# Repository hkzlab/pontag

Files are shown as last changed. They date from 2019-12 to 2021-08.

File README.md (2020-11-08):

# PONTAG
## Introduction
PONTAG is a board that converts a PS/2 mouse into a serial mouse that can be used on old IBM PC and clones, which lacked PS/2 ports but had plenty of serial interfaces (especially if expansion cards are installed).

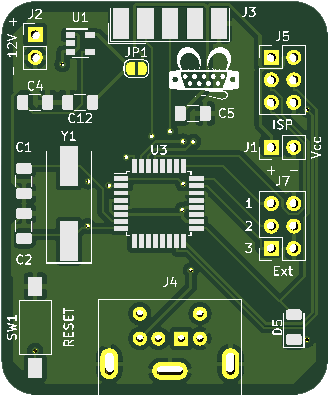
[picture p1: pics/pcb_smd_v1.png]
Rev. 1 PCB


## Features & Limitations
* Supports 3 buttons+wheel PS/2 mouses and converts their protocol to RS232 serial usable on old PC systems.
* The board requires an external power supply between 8V and 12V to power the MCU and mouse
* Detects PS/2 mouses with wheel and without and notifies the user via LED (5 fast blinks for a normal mouse, 20 fast blinks for a mouse with wheel)
* Can be configured for various resolutions and mouse protocols by pushing mouse buttons

### Configuration
The board can be configured during powerup by pressing the mouse keys. The configuration will be retained for all subsequent boots.
To configure the board you must keep the mouse button pressed during a reset/bootup. A sequence of **15 slow blinks** will notify the user of the accepted command, then the board will be reset with the new configuration.

* **Left mouse button pressed**: Switches between simple Microsoft protocol and Microsoft protocol with wheel (**DEFAULT:** MS+Wheel)
* **Right mouse button pressed**: Switches mouse resolution, switching between 1, 2, 4 or 8 counts per mm traveled (**DEFAULT:** 4 counts per mm)
* **Both buttons pressed**: Resets the board to defaults

### Extra Header
The board supports some special options that can be toggled via external header, shorting the corrisponding pin to GND.

* **Pin 1**: The board will enter debug mode, and start printing debug strings on the serial port. It will NOT work as a mouse.
* **Pin 2**: If jumpered, the board enter power save mode after 3 minutes of mouse inactivity.
* **Pin 3**: If shorted, forces the use of the simple Microsoft protocol (2 buttons, no wheel), regardless of what is stored in the EEPROM.
* **Pin 4**: If jumpered, the board will skip the PS/2 intellimouse wheel activation sequence. (**not exposed on board 1.0 !!!**)

## Supported protocols
PONTAG emulates a Microsoft 3-buttons Wheel serial mouse by default and transmits the `0x4D 0x5A 0x40 0x00 0x00 0x00` detection string when RTS signal is toggled.

The boards are tested with [CuteMouse](http://cutemouse.sourceforge.net/).

## Credits

- Some footprints are taken from [4x1md](https://github.com/4x1md/kicad_libraries)
- Took and modified PS/2 code from [sensi.org](http://sensi.org/~svo/%5Bm%5Douse/) and [mouse1351](https://github.com/svofski/mouse1351)

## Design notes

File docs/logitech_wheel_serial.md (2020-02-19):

A logitech serial mouse with wheel presents itself with the following sequence:
```
0x4D - 'M'
0x5A - 'Z'
0x40 - '@'
0x00
0x00
0x00
```

These bytes are also followed by this sequence
```
0x08 0x01 0x24 0x2c
0x27 0x29 0x18 0x10
0x15 0x10 0x3c 0x3c
0x2d 0x2f 0x35 0x33
0x25 0x3c 0x30 0x2e
0x30 0x10 0x26 0x10
0x18 0x0c 0x30 0x2e
0x30 0x10 0x26 0x10
0x23 0x18 0x22 0x09 
```
It also communicates with the standard 4-byte Microsoft wheel mouse protocol

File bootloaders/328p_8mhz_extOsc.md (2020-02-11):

# BOARD
This configuration is for a `ATMega328P` with an 8Mhz crystal external oscillator connected.

## Bootloader config
Optiboot is configured for a baudrate of `38400`, 8Mhz clock.
Led is on port `B5` and flashes 6 times.

## Fuses
Suggested fuses are:

- LFUSE 0xDE
- HFUSE 0xDE
- EFUSE 0xFC

### Example programming
```
avrdude  -c dragon_isp -p atmega328p -e -u -U efuse:w:0xFC:m -U hfuse:w:0xDE:m -U lfuse:w:0xDE:m -U flash:w:optiboot_atmega328.hex
```

You can then access it via the serial port:
```
avrdude  -c arduino -p atmega328p -P /dev/ttyUSB0 -b38400
```

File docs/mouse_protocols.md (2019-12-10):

# Mouse Protocols

## Microsoft serial mouse

### Description

The Microsoft serial mouse is the most popular 2 button mouse.
It is supported by all major operating systems.

The maximum tracking rate for a Microsoft mouse is 40 reports/second * 127 counts per report, in other words, 5080 counts per second.
The most common range for mice is is 100 to 400 CPI (counts per inch) but can be up to 1000 CPI.
A 100CPI mouse can discriminate motion up to 50.8 inches/second while a 400 CPI mouse can only discriminate motion up to 12.7 inches/second.

### Pinout
```
9 pin  25 pin    Line    Comments
shell  1         GND
3      2         TD      Serial data from host to mouse (only for power)
2      3         RD      Serial data from mouse to host
7      4         RTS     Positive voltage to mouse
8      5         CTS
6      6         DSR
5      7         SGND
4      20        DTR     Positive voltage to mouse and reset/detection

RTS = Request to Send   CTS  = Clear to Send
DSR = Data Set Ready    DTR  = Data Terminal Ready
GND = Protective Ground SGND = Signal Ground
```

To function correctly, both the RTS and DTR lines must be positive.
DTR/DSR and RTS/CTS must NOT be shorted.

RTS may be toggled negative for at least 100ms to reset the mouse. 
(After a cold boot, the RTS line is usually negative. This provides an automatic toggle when RTS is brought positive).
When DTR is toggled the mouse should send a single byte 0x45 (ASCII 'M').

### Serial data parameters:
1200bps, 7 databits, 1 stop-bit

### Data packet format:
Data is sent in 3 byte packets for each event (a button is pressed or released or the mouse moves):

```
        D7      D6      D5      D4      D3      D2      D1      D0

Byte 1  X       1       LB      RB      Y7      Y6      X7      X6
Byte 2  X       0       X5      X4      X3      X2      X1      X0      
Byte 3  X       0       Y5      Y4      Y3      Y2      Y1      Y0

LB is the state of the left button (1 means down)
RB is the state of the right button (1 means down)
X7-X0 movement in X direction since last packet (signed byte)
Y7-Y0 movement in Y direction since last packet (signed byte)
```

The high order bit of each byte (D7) is ignored. Bit D6 indicates the start of an event, which allows the software to synchronize with the mouse.

### Graphical representation of a packet
```
              1st byte        2nd byte         3rd byte
          ================  ===============  ================
           - 1 ? ? Y Y X X  - 0 X X X X X X  - 0 Y Y Y Y Y Y
          ================  ===============  ================
               | | \ / \ /      \---------/      \---------/
               | |  |   |            |                |
               | |  |   \----\       |                |
               | |  \--------|-------|--------\       |
               | |          / \ /---------\  / \ /---------\
               | |         ================ =================
               | |          0 0 0 0 0 0 0 0  0 0 0 0 0 0 0 0
 Left Button --/ |         ================ =================
Right Button ----/            X increment      Y increment
```

### 3 Button Logitech extension
Logitech extended the 2 button mouse protocol to support 3 button mice by adding a 4th byte when the middle button is pressed (and the first packet after it is released).
If a 4th byte is encountered (i.e., an extra byte with D6 set to 0) then D5 of that byte (0x20) indicates the status of the middle mouse button.

## Mouse systems mouse
### Serial data parameters:
1200bps, 8 databits, 1 stop-bit

### 5 byte Mouse Systems packet
```
        D7      D6      D5      D4      D3      D2      D1      D0

Byte 1  1       0       0       0       0       LB      CB      RB
Byte 2  X7      X6      X5      X4      X3      X2      X1      X0
Byte 3  Y7      Y6      Y5      Y4      Y3      Y4      Y1      Y0
Byte 4  X7'     X6'     X5'     X4'     X3'     X2'     X1'     X0'
Byte 5  Y7'     Y6'     Y5'     Y4'     Y3'     Y4'     Y1'     Y0'

LB is left button state (0=pressed, 1=released)
CB is center button state (0=pressed, 1=released)
RB is right button state (0=pressed, 1=released)
X7-X0 movement in X direction since last packet in signed byte 
      format (-128..+127), positive direction right
Y7-Y0 movement in Y direction since last packet in signed byte 
      format (-128..+127), positive direction up
X7'-X0' movement in X direction since sending of X7-X0 packet in signed byte 
      format (-128..+127), positive direction right
Y7'-Y0' movement in Y direction since sending of Y7-Y0 in signed byte 
      format (-128..+127), positive direction up
```

The last two bytes in the packet (bytes 4 and 5) contain information about movement data changes which have occured after data bytes 2 and 3 have been sent.

## PS/2 mouse
The standard PS/2 mouse (such as the Logitech mouse) defaults to 160 CPI and can be switched to 40, 80, 160 or 320 CPI via software. The Microsoft mouse driver for Windows 3.x and Windows 95 defaults to 160 counts per inch. The maximum tracking rate for PS/2 mouse is 40 reports/second * 255 counts per report, or 10200 counts per second. A 100 CPI mouse could discriminate motion up to 102 inches per second while a 400 CPI mouse could discriminate motion up to 25.2 inches per second.

### Connector pinout
```
Pin     Wire Name
1       DATA
2       Reserved
3       Ground
4       +5V Supply
5       CLK
6       Reserved
Shield  Chassis
```

### Packet Format
```
        D7      D6      D5      D4      D3      D2      D1      D0
Byte 1  XV      XV      YS      XS       1       M       R       L
Byte 2  X7      X6      X5      X4      X3      X2      X1      X0
Byte 3  Y7      Y6      Y5      Y4      Y3      Y2      Y1      Y0

L       Left button state (1 = pressed down)
M	Middle button state (1 = pressed down)
R       Right button state (1 = pressed down)
X0-X7   Movement in X direction
Y0-Y7   Movement in Y direction
XS,YS   Movement data sign bits (1 = negative)
XV,YV   Movement data overflow bits (1 = overflow has occured)
```

### Physical connector
The PS/2 mouse connector has the following pinout when looking at the connector on the back of the computer:
```
        4 u 6
       1  .  2
        3   5

1\.      GND
2\.      +5V
3\.      DATA
4\.      CLOCK
5\.      Not used
6\.      Not used
```

Bi-directional transmission is controlled by the CLK and DATA lines.
Both are fed by an open collector device which lets either host or mouse force the line to "0".
During non-transmission, CLK is at "1" and DATA can be at "0" or "1".

The host can inhibit mouse transmission by forcing CLK to "0".
If the host inhibits the mouse while it is transmitting, the byte must be retransmitted (if the inhibit state arrived before the 11th clock).

#### Receiving
Receiving data: Check 'clock'.
If inactive, there is a bit on the 'data' line.
Each transmission unit is one start bit, eight data bits, odd parity and one stop bit. Start bits are low, stop bits high.
Each clock active or inactive period is 30 to 50 microseconds. Data transition to falling edge of clock is 5 to 25 microseconds.

#### Sending
Sending: Check that both clock and data are high.
Pull down data for start bit, and start clocking.

**NOTE:** Logitech has made the extension to this protocol to allow three buttons (the M bit is always 0 on 2 button mice).

## References
* [Original PC mouse info page by Tomi Engdahl](http://www.hut.fi/~then/mytexts/mouse.html)
* PC Magazine May 28, 1991
* [Programmer's Reference to Genius Mouse](ftp://x2ftp.oulu.fi/pub/msdos/programming/docs/gmouse.doc)
* [Logitech Pointing Device Hardware Information Product Support Document # 1410](ftp://ftp.logitech.com/pub/TechSupport/MOUSE/HELP/1410.txt)
* [Mice: How do they work?](http://box.argonet.co.uk/users/4qd/meece.html) by [Richard Torrens](mailto:4qd@argonet.co.uk)
* In Pursuit Of The Perfect Portable Pointer by Intelink Electronics from [EDN Products Edition](http://www.ednprodmag.com/) April 16, 1977 pages 43-45
* [Programming the Microsoft Mouse](http://www.geocities.com/SiliconValley/2151/mouse.html)

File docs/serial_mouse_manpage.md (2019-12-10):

# Serial Mouse Interface
The following text is taken from the linux [man page](https://www.systutorials.com/docs/linux/man/4-mouse/) about the serial mouse interface.

## Introduction
The pinout of the usual 9 pin plug as used for serial mice is:
```
pin name  used for
2   RX	  Data
3   TX	  -12 V, Imax = 10 mA
4   DTR	  +12 V, Imax = 10 mA
7   RTS	  +12 V, Imax = 10 mA
5   GND	  Ground
```
This is the specification, in fact 9 V suffices with most mice.

### Initialization
The mouse driver can recognize a mouse by **dropping RTS to low and raising it again**.
About **14 ms** later the mouse will send **0x4D** ('M') on the data line.
After a further **63 ms**, a Microsoft-compatible 3-button mouse will send **0x33** ('3').
The relative mouse movement is sent as dx (positive means right) and dy (positive means down).

#### Speed selection
Various mice can operate at different speeds.
To select speeds, cycle through the speeds 9600, 4800, 2400, and 1200 bit/s, each time writing the two characters from the table below and waiting **100 ms**.
The following table shows available speeds and the strings that select them:
```
bit/s   string
9600    *q
4800    *p
2400    *o
1200    *n
```
The first byte of a data packet can be used for synchronization purposes.

## Protocols
### Microsoft protocol
The Microsoft protocol uses **1 start bit**, **7 data bits**, **no parity** and **one stop bit** at the speed of **1200 bits/sec**.
Data is sent to RxD in **3-byte packets**. The dx and dy movements are sent as two's-complement, lb (rb) are set when the left (right) button is pressed:
```
byte    d6  d5  d4  d3  d2  d1  d0
   1     1  lb  rb  dy7 dy6 dx7 dx6
   2     0  dx5 dx4 dx3 dx2 dx1 dx0
   3     0  dy5 dy4 dy3 dy2 dy1 dy0
```

#### 3-button Microsoft protocol
Original Microsoft mice only have two buttons. However, there are some three button mice which also use the Microsoft protocol.
Pressing or releasing the middle button is reported by sending a packet with zero movement and no buttons pressed.
(Thus, unlike for the other two buttons, the status of the middle button is not reported in each packet.)

### Logitech protocol
Logitech serial 3-button mice use a different extension of the Microsoft protocol: when the middle button is up, the above 3-byte packet is sent.
When the middle button is down a 4-byte packet is sent, where the 4th byte has value 0x20 (or at least has the 0x20 bit set).
In particular, a press of the middle button is reported as 0,0,0,0x20 when no other buttons are down.

### Mousesystems protocol
The Mousesystems protocol uses 1 start bit, 8 data bits, no parity and two stop bits at the speed of 1200 bits/sec.
Data is sent to RxD in 5-byte packets. dx is sent as the sum of the two two's-complement values, dy is send as negated sum of the two two's-complement values.
lb (mb, rb) are cleared when the left (middle, right) button is pressed:
```
byte    d7   d6   d5   d4   d3   d2   d1   d0
   1     1    0    0    0    0   lb   mb   rb
   2     0 dxa6 dxa5 dxa4 dxa3 dxa2 dxa1 dxa0
   3     0 dya6 dya5 dya4 dya3 dya2 dya1 dya0
   4     0 dxb6 dxb5 dxb4 dxb3 dxb2 dxb1 dxb0
   5     0 dyb6 dyb5 dyb4 dyb3 dyb2 dyb1 dyb0
```
Bytes 4 and 5 describe the change that occurred since bytes 2 and 3 were transmitted.

### Sun protocol
The Sun protocol is the 3-byte version of the above 5-byte Mousesystems protocol: the last two bytes are not sent.

## MM protocol
The MM protocol uses 1 start bit, 8 data bits, odd parity and one stop bit at the speed of 1200 bits/sec.
Data is sent to RxD in 3-byte packets. dx and dy are sent as single signed values, the sign bit indicating a negative value.
lb (mb, rb) are set when the left (middle, right) button is pressed:
```
byte    d7   d6   d5   d4   d3   d2   d1   d0
   1     1    0    0  dxs  dys   lb   mb   rb
   2     0  dx6  dx5  dx4  dx3  dx2  dx1  dx0
   3     0  dy6  dy5  dy4  dy3  dy2  dy1  dy0
```

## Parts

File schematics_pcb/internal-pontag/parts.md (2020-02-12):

# Pontag proto 00
## Parts list
### ICs
- U1 - 78L05 TO92 regulator
- U3 - ATMega328P
- U4 - MAX232

### Resistors
- R1 - 1M ohm resistor
- R2 - 470 ohm resistor
- R3,R4 - 5K ohm resistors
- R5 - 10K ohm resistors

### Capacitors
- C1,C2 - 22pF disc ceramic capacitors
- C3,C8-C11 - 1.0uF/25V electrolytic capacitors
- C4 - 10nF ceramic capacitor
- C5,C6 - 100nF ceramic capacitors
- C7 - 1.0uF ceramic capacitor

### Diodes
- D1-D3 - 1n4148 silicon diodes
- D4 - 1n4001 diode
- D5 - LED

### Headers & Connectors
- J1 - 02x02 2.54mm header
- J2 - 01x02 2.54mm header
- J3 - DB9 female connector
- J4 - 6pin Mini-din female connector
- J5 - 02x03 2.54mm header
- J6 - 01x02 2.54mm header
- J7 - 02x06 2.54mm header
- JP1 - 01x02 2.54mm header
- JP2 - 01x02 2.54mm header

### Misc
- SW1 - 4pin push button
- Y1 - 8Mhz crystal

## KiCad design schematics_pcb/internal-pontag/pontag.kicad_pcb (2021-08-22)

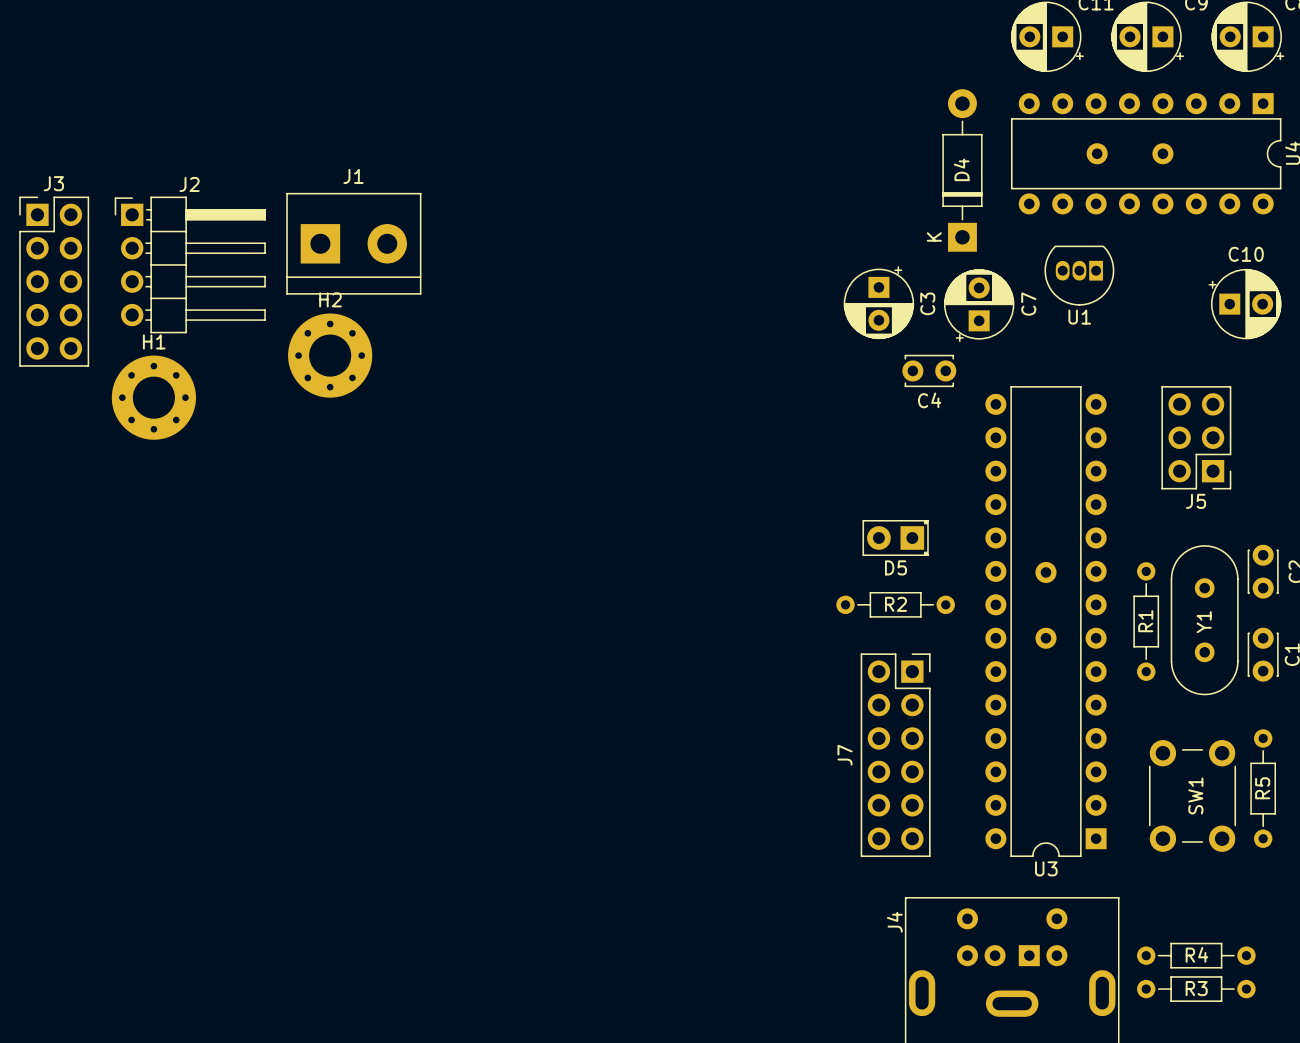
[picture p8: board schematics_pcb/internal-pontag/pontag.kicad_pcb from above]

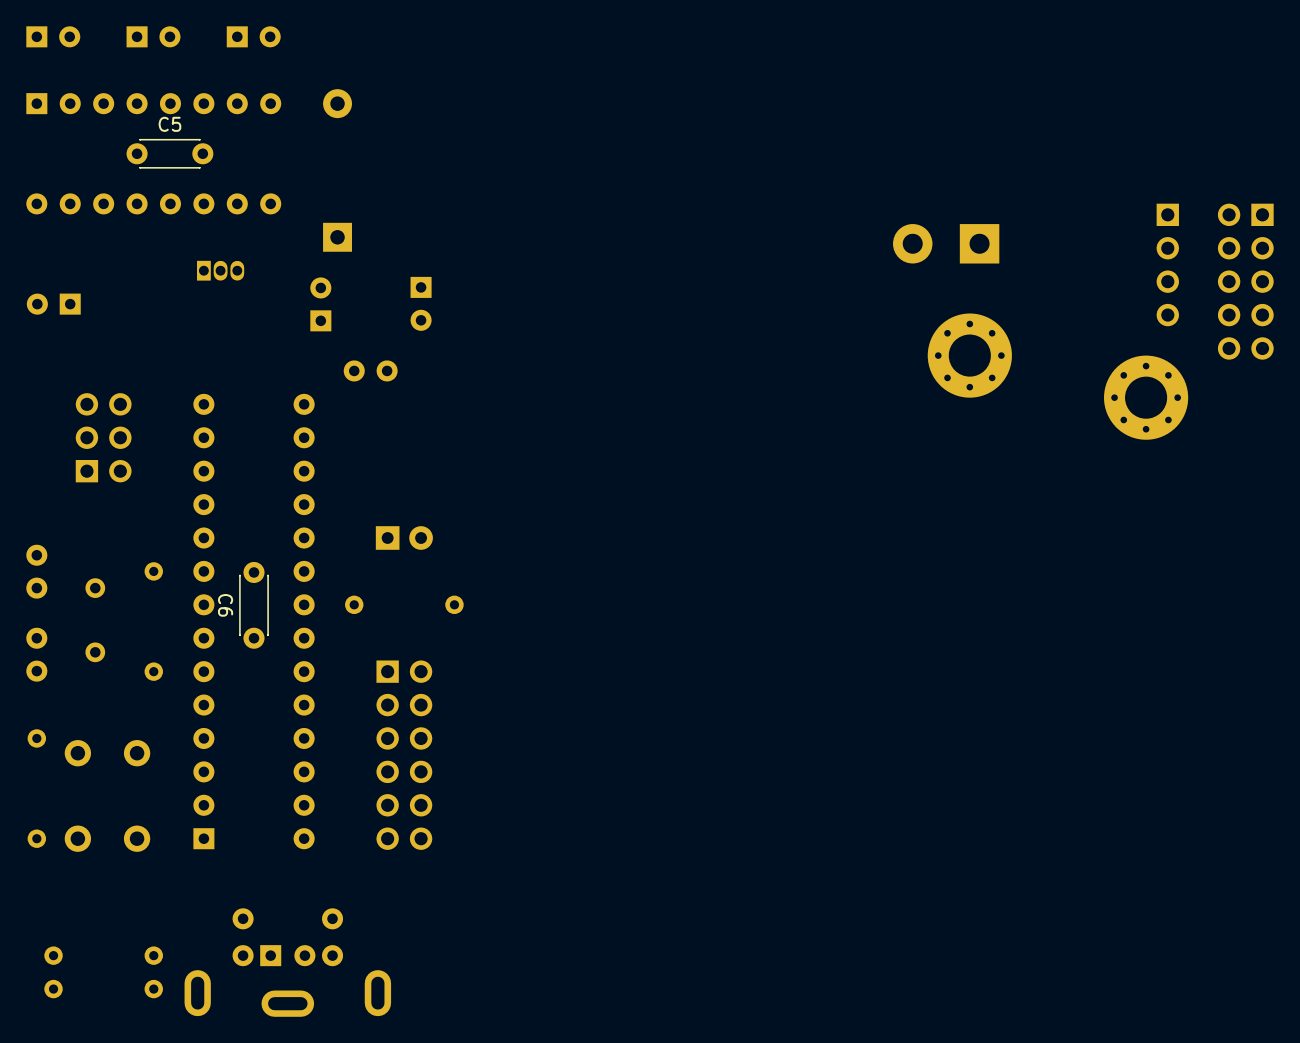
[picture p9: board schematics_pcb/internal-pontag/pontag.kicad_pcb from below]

Board: 2 copper layers, 31 parts (2 on the bottom side), 31 nets, no tracks yet.

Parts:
C1, C2: 22pF; C_Disc_D3.0mm_W2.0mm_P2.50mm
C3, C7, C8, C9, C10, C11: 1.0uF; CP_Radial_D5.0mm_P2.50mm
C4: 10nF; C_Disc_D3.4mm_W2.1mm_P2.50mm
C5, C6: 100nF; C_Disc_D4.3mm_W1.9mm_P5.00mm
D4: 1N4001; D_DO-41_SOD81_P10.16mm_Horizontal
D5: LED; LED_D2.0mm_W4.8mm_H2.5mm_FlatTop
H1, H2: MountingHole_Pad; MountingHole_3.2mm_M3_Pad_Via
J1: PWR Connector; TerminalBlock_bornier-2_P5.08mm
J2: Floppy PWR Connector; PinHeader_1x04_P2.54mm_Horizontal
J3: RS232 Port; PinHeader_2x05_P2.54mm_Vertical
J4: PS/2 Mouse; Connector_Mini-DIN_Female_6Pin_2rows
J5: AVR-ISP-6; PinHeader_2x03_P2.54mm_Vertical
J7: Extra; PinSocket_2x06_P2.54mm_Vertical
R1: 1M; R_Axial_DIN0204_L3.6mm_D1.6mm_P7.62mm_Horizontal
R2: 470; R_Axial_DIN0204_L3.6mm_D1.6mm_P7.62mm_Horizontal
R3, R4: 5K; R_Axial_DIN0204_L3.6mm_D1.6mm_P7.62mm_Horizontal
R5: 10K; R_Axial_DIN0204_L3.6mm_D1.6mm_P7.62mm_Horizontal
SW1: Reset; SW_PUSH_6mm
U1: L78L05_TO92; TO-92_Inline
U3: ATmega328P-PU; DIP-28_W7.62mm
U4: MAX232; DIP-16_W7.62mm
Y1: 8.0Mhz; Crystal_HC49-U_Vertical

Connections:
+12V: C3.1, D4.1, U1.3
/MISO: J5.1, U3.18
/MOSI: J5.4, U3.17
/PS2-CLOCK: J4.5, R4.2, U3.4
/PS2-DATA: J4.1, R3.2, U3.6
/RESET: J5.5, R5.1, SW1.2, U3.1
/RS232-RTS: J3.7, U4.13
/RS232-RX: J3.2, U4.7
/RS232-TX: J3.3, U4.8
/SCK: D5.2, J5.3, U3.19
/TTL-CTS: U3.5, U4.12
/TTL-RX: U3.2, U4.9
/TTL-TX: U3.3, U4.10
/XTAL1: C1.2, R1.1, U3.9, Y1.2
/XTAL2: C2.2, R1.2, U3.10, Y1.1
GND: C1.1, C2.1, C3.2, C4.2, C5.2, C6.2, C7.2, C11.1, H1.1, H2.1, J1.2, J2.2, J2.3, J3.5, J4.3, J4.7, J5.6, J7.2, J7.4, J7.6, J7.8, J7.10, J7.12, R2.2, SW1.1, U1.2, U3.8, U3.22, U4.11, U4.15
unnamed: C8.1, U4.1
unnamed: C8.2, U4.3
unnamed: C9.1, U4.4
unnamed: C9.2, U4.5
unnamed: C10.1, U4.2
unnamed: C11.2, U4.6
unnamed: D4.2, J1.1, J2.4
unnamed: D5.1, R2.1
unnamed: J7.1, U3.23
unnamed: J7.3, U3.24
unnamed: J7.5, U3.25
unnamed: J7.7, U3.26
unnamed: J7.9, U3.27
unnamed: J7.11, U3.28
VCC: C4.1, C5.1, C6.1, C7.1, C10.2, J4.4, J5.2, R3.1, R4.1, R5.2, U1.1, U3.7, U3.20, U3.21, U4.16

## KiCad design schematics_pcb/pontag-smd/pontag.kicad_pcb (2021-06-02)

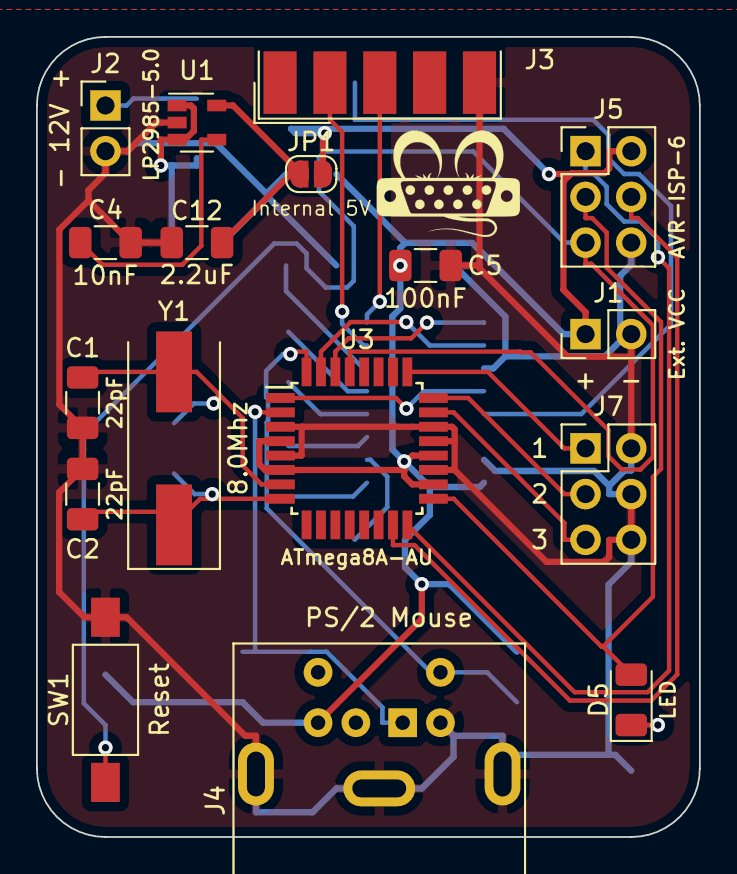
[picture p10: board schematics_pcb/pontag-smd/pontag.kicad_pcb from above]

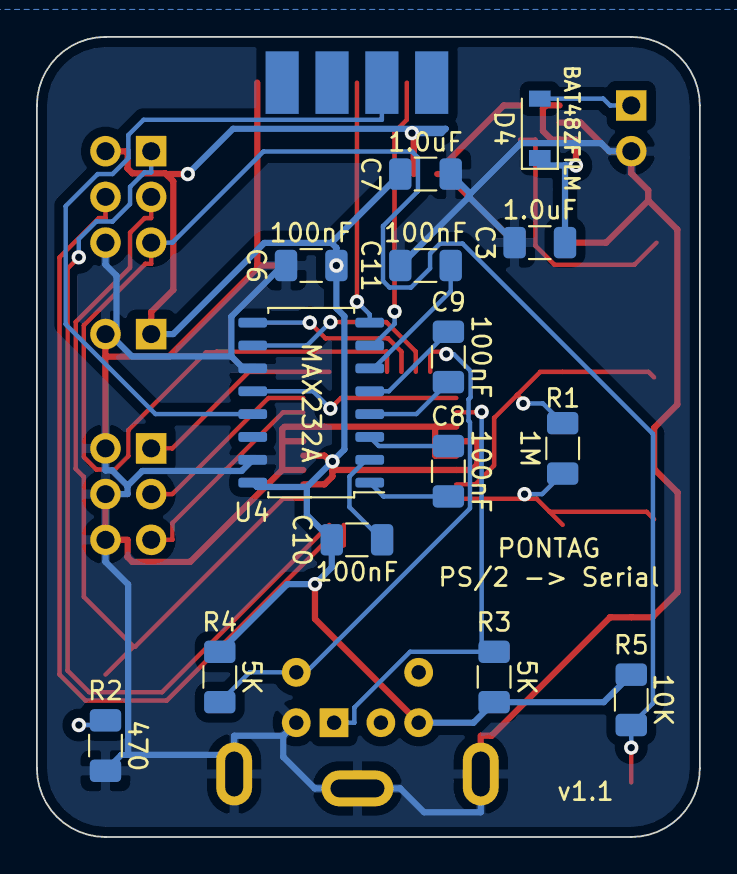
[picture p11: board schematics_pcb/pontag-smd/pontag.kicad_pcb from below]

Board: 2 copper layers, 36.8 x 44.5 mm, 31 parts (14 on the bottom side), 30 nets.

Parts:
C1, C2: 22pF; C_1206_3216Metric
C3, C7: 1.0uF; C_1206_3216Metric
C4: 10nF; C_1206_3216Metric
C5, C6, C8, C9, C10, C11: 100nF; C_1206_3216Metric
C12: 2.2uF; C_1206_3216Metric
D4: BAT48ZFILM; D_SOD-123
D5: LED; LED_1206_3216Metric
J1: Ext. VCC; PinHeader_1x02_P2.54mm_Vertical
J2: External 12V; PinHeader_1x02_P2.54mm_Vertical
J3: RS232 Port; DSUB-9_Female_EdgeMount_P2.77mm
J4: PS/2 Mouse; Connector_Mini-DIN_Female_6Pin_2rows
J5: AVR-ISP-6; PinHeader_2x03_P2.54mm_Vertical
J7: Extra; PinHeader_2x03_P2.54mm_Vertical
JP1: Internal 5V; SolderJumper-2_P1.3mm_Open_RoundedPad1.0x1.5mm
R1: 1M; R_1206_3216Metric
R2: 470; R_1206_3216Metric
R3, R4: 5K; R_1206_3216Metric
R5: 10K; R_1206_3216Metric
SW1: Reset; SW_SPST_FSMSM
U1: LP2985-5.0; SOT-23-5
U3: ATmega8A-AU; TQFP-32_7x7mm_P0.8mm
U4: MAX232A; SOIC-16_4.55x10.3mm_P1.27mm
Y1: 8.0Mhz; Crystal_SMD_HC49-SD

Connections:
+12V: C3.1, D4.1, U1.1, U1.3
/MISO: J5.1, U3.16
/MOSI: J5.4, U3.15
/PS2-CLOCK: J4.5, R4.2, U3.32
/PS2-DATA: J4.1, R3.2, U3.2
/REG_5V: C12.1, JP1.1, U1.5
/RESET: J5.5, R5.2, SW1.1, U3.29
/RS232-RTS: J3.7, U4.13
/RS232-RX: J3.2, U4.7
/RS232-TX: J3.3, U4.8
/SCK: D5.2, J5.3, U3.17
/TTL-CTS: U3.1, U4.12
/TTL-RX: U3.30, U4.9
/TTL-TX: U3.31, U4.10
/XTAL1: C1.2, R1.1, U3.7, Y1.2
/XTAL2: C2.2, R1.2, U3.8, Y1.1
GND: C1.1, C2.1, C3.2, C4.2, C5.2, C6.2, C7.2, C11.2, C12.2, J1.2, J2.2, J3.5, J4.3, J4.7, J5.6, J7.2, J7.4, J7.6, R2.2, SW1.2, U1.2, U3.3, U3.5, U3.19, U3.21, U3.22, U4.11, U4.15
unnamed: C4.1, U1.4
unnamed: C8.1, U4.1
unnamed: C8.2, U4.3
unnamed: C9.1, U4.4
unnamed: C9.2, U4.5
unnamed: C10.1, U4.2
unnamed: C11.1, U4.6
unnamed: D4.2, J2.1
unnamed: D5.1, R2.1
unnamed: J7.1, U3.25
unnamed: J7.3, U3.24
unnamed: J7.5, U3.23
VCC: C5.1, C6.1, C7.1, C10.2, J1.1, J4.4, J5.2, JP1.2, R3.1, R4.1, R5.1, U3.4, U3.6, U3.18, U3.20, U4.16

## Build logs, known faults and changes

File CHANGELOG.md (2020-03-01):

# Changelog
## 1.0 branch
### 1.1.5 (2020.03.01)
- **FIX**: Send the actual reset packets as 7n1, whoops

### 1.1.4 (2020.02.17)
- **NEW**: Add pin header to disable PS/2 wheel detection

### 1.1.3 (2020.02.16)
- **FIX**: Add a timeout to READID and READSTATUS functions with a default return value. Some mouses seems not to respond to these commands (found a cheap *SAFEWAY* that did this) and this caused the board to reset.

### 1.1.2 (2020.02.16)
- **NEW**: Add DEBUG mode that can be enabled by shorting the 2nd config header to GND.

### 1.1.1 (2020.02.15)
- **FIX**: Correctly read device id even if the device sends an 0xFA or an 0xFC before the actual response

### 1.1.0 (2020.02.15)
- **FIX**: Correctly read mouse status even if the device sends an 0xFA (ACK) before the actual response

- **NEW**: Supports configuration via mouse buttons

### 1.0.2 (2020.02.14)
- **FIX**: Do not uselessly repeat the detection string when `RTS` is toggled

- **NEW**: Replace Logitech 3-button mouse support with Microsoft Wheel mouse support
- **NEW**: Add option to switch between wheel mouse and normal microsoft mouse using options header
- **NEW**: Support for PS/2 Wheel mouses with support for Intellimouse 4-byte protocol

- **MISC**: Added pcb libraries back in the repo

### 1.0.1 (2020.02.12)
- **FIX**: PONTAG now identifies itself as a 3 button Logitech mouse by sending the code `M3` when `RTS` is toggled

- **MISC**: Cleanup docs and reorganized board files

### 1.0.0 (2020.02.12)
- **NEW**: First version, with support for `ATMega328p` and `ATMega8a`

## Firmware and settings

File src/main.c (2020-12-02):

#include <stdint.h>
#include <stdio.h>
#include <stdlib.h>

#include <util/delay.h>

#include <avr/io.h>
#include <avr/wdt.h>
#include <avr/interrupt.h>
#include <avr/sleep.h>

#include "ioconfig.h"
#include "ps2.h"
#include "ps2_mouse.h"
#include "ps22ser.h"
#include "pconfig.h"

#include "uart.h"
#include "millis.h"

#include "main.h"

#define VERSION "1.2.1"

#define SLEEP_DELAY_TIME 180000 //  3 minutes without movement before we put the micro to sleep

#define PS2_WHL_PKT_SIZE 4
#define PS2_STD_PKT_SIZE 3

typedef union {
    struct {
        uint8_t default_proto : 1; // if 1, default protocol is enabled, if 0, MS protocol is forced
        uint8_t powersave : 1; // if 1, we enable powersave after 2 minutes idle
        uint8_t standard_mode : 1; // if 1, the board runs normally, if 0, the board enters debug mode
        uint8_t wheel_detect : 1; // if 1, we try PS/2 wheel detection
        uint8_t unused : 2;
    } u;
    uint8_t header;
} HeaderOptions;

static void rts_init(void);

static void setLED(uint8_t status);
static void blinkLED(uint8_t times, uint8_t fast); // Blink the led X times either fast (50ms) or slow (100ms)
static void soft_reset(void);

static void update_configuration(uint8_t buttons, ConfigStruct *cfg);

static void sendMSPkt(void);
static void sendMSWheelPkt(void);
static void sendDebugPkt(void);

static void sleepMode(uint8_t debug);

// Vars
static volatile uint8_t rts_disable_xmit = 0;
static void (* volatile sendDetectPkt)(void) = &sendMSWheelPkt;

int main(void) {
    HeaderOptions opts;
    ConfigStruct cfg;

    uint8_t serial_pkt_buf[4]; // Buffer for serial packets
    uint8_t ps2_pkt_buf[PS2_WHL_PKT_SIZE] = {0x00, 0x00, 0x00, 0x00}; // Buffer for ps/2 packets
    uint8_t converter_result; // Instanteneous result of the conversion
    uint8_t ps2_buf_counter = 0;
    uint8_t init_res = 0; // Init codes
    uint8_t ps2_pkt_size = 0;

    uint8_t cfg_force_ms = 0;

#if defined (__AVR_ATmega328P__)
    wdt_enable(WDTO_4S); // Enable the watchdog to reset in 4 seconds...
#elif defined (__AVR_ATmega8A__)
    wdt_enable(WDTO_2S); // Enable the watchdog to reset in 2 seconds...
#endif

    // Initialize the I/O and communications
    io_init();

    // Read the option header
    opts.header = OPTPIN;
    // Read the config from EEPROM
    read_perm_config(&cfg);
    
    // Option header always wins over stored config
    if(!opts.u.default_proto || cfg.cfg_data.c.proto) cfg_force_ms = 1; // We're enforcing simple Microsoft protocol
    else cfg_force_ms = 0; // Enable mouse wheel protocol

    // Set which type of identification code we'll send
    if(!opts.u.standard_mode) sendDetectPkt = sendDebugPkt;
    else if(cfg_force_ms) sendDetectPkt = sendMSPkt;

    // Initialize RTS interrupt and PS2
    rts_init();
    ps2_init();

    // First watchdog kick
    wdt_reset();

    // Initialize serial port
    uart_init();
    stdout = &uart_output;
    stdin  = &uart_input;

    // Initialize millisecond counter
    millis_init();

    // Enable interrupts
    sei();

    // Clear some vars
    rts_disable_xmit = 0;

    setLED(1); // Turn the LED on

    uart_enable();

    if(!opts.u.standard_mode) {
        wdt_reset();
        printf(" Board initialized! - %s\n", VERSION);
        printf(" -- hdr -> proto:%u standard:%u pwrsave:%u wheel:%u\n", opts.u.default_proto, opts.u.standard_mode, opts.u.powersave, opts.u.wheel_detect);
        printf(" -- cfg -> proto:%u res:%u\n", cfg.cfg_data.c.proto, cfg.cfg_data.c.res);
        printf(" -- Initializing PS/2 Mouse\n");
        wdt_reset();
    }

    init_res = mouse_init(cfg.cfg_data.c.res, opts.u.wheel_detect); // Initialize the mouse

    if(!opts.u.standard_mode) printf(" -- Initializing result %02X\n", init_res);
    
    // Check if we need to update the configuration
    update_configuration(init_res & MOUSE_BTN_MASK, &cfg);

    // Set the PS/2 packet size
    if(init_res & MOUSE_EXT_MASK) ps2_pkt_size = PS2_WHL_PKT_SIZE;
    else ps2_pkt_size = PS2_STD_PKT_SIZE;

    wdt_reset(); // kick the watchdog again...

    // Notify which mouse we found
    if (init_res & MOUSE_ERR_MASK) blinkLED(2, 1);
    else if(init_res & MOUSE_EXT_MASK) blinkLED(25, 1);
    else blinkLED(10, 1);

    uint32_t last_pkt_time = millis();
    uint32_t now = last_pkt_time;

    while(1) {
        now = millis();
        if(now < last_pkt_time) last_pkt_time = now; // Rollover...

        wdt_reset(); // Kick the watchdog

        while(ps2_avail()) {
            last_pkt_time = now;

            ps2_pkt_buf[ps2_buf_counter] = ps2_getbyte();
            
            // Wait for a packet that has fixed bit 3 at 1, this is an attempt at a resync
            if(!ps2_buf_counter && !(ps2_pkt_buf[ps2_buf_counter] & 0x08)) continue;

            ps2_buf_counter = (ps2_buf_counter + 1) % ps2_pkt_size;

            if(!ps2_buf_counter) {
                converter_result = ps2bufToSer(ps2_pkt_buf, serial_pkt_buf);

                if(converter_result && !rts_disable_xmit) {
                    ps2_enable_recv(0); // Ok, stop receiving for now

                    // debug prints
                    if(!opts.u.standard_mode) {
                        printf("PS/2  <-- %02X %02X %02X %02X\n", ps2_pkt_buf[0], ps2_pkt_buf[1], ps2_pkt_buf[2], ps2_pkt_buf[3]);
                        printf("RS232 --> %02X %02X %02X %02X\n\n", serial_pkt_buf[0], serial_pkt_buf[1], serial_pkt_buf[2], serial_pkt_buf[3]);
                    } else { // Running normally
                        // Transmit the converted data to the serial port
                        uart_putchar(serial_pkt_buf[0], NULL);
                        uart_putchar(serial_pkt_buf[1], NULL);
                        uart_putchar(serial_pkt_buf[2], NULL);
                        if(!cfg_force_ms) uart_putchar(serial_pkt_buf[3], NULL); // Send the fourth byte, according to the Microsoft Wheel mouse specs
                    }

                    ps2_enable_recv(1); // Back to getting data!
                }
            }
        }

        if(!opts.u.powersave && ((now - last_pkt_time) > SLEEP_DELAY_TIME)) { 
            sleepMode(!opts.u.standard_mode);
            last_pkt_time = millis();
            ps2_buf_counter = 0;
        }
    }

    return 0;
}

static void rts_init(void) {
    // Enable INT1, and have it toggle at any logical level change
#if defined (__AVR_ATmega328P__)
    // Toggle at the rising edge
    EICRA |= _BV(ISC10);
    EICRA &= ~_BV(ISC11);
    EIMSK |= _BV(INT1);
#elif defined (__AVR_ATmega8A__)
    MCUCR |= _BV(ISC10);
    MCUCR &= ~_BV(ISC11);
    GICR  |= _BV(INT1);
#endif
}

static void setLED(uint8_t status) {
    if(!status) LEDPORT &= ~(_BV(LED_P)); // Turn the LED off
    else LEDPORT |= _BV(LED_P); // Turn the LED on
}

static void blinkLED(uint8_t times, uint8_t fast) {
    setLED(0);

    while(times--) {
        wdt_reset();

        setLED(1);
        fast ? _delay_ms(50) : _delay_ms(100);
        setLED(0);
        fast ? _delay_ms(50) : _delay_ms(100);
    }
}

ISR(INT1_vect) { // Manage INT1
    rts_disable_xmit = 1; // Avoid further transmission from the code in the main loop

    sendDetectPkt();
    _delay_ms(10);

    rts_disable_xmit = 0; // Allow transmission again
}

static void sendMSPkt(void) {
    uart_putchar('M' | 0x80, NULL);
}

static void sendMSWheelPkt(void) {
    uart_putchar('M' | 0x80, NULL);
    uart_putchar('Z' | 0x80, NULL);
    uart_putchar('@' | 0x80, NULL);
    uart_putchar(0x80, NULL);
    uart_putchar(0x80, NULL);
    uart_putchar(0x80, NULL);
}

static void sendDebugPkt(void) {
    printf("DETECT_PKT\n");
}

static void update_configuration(uint8_t buttons, ConfigStruct *cfg) {
    switch(buttons & 0x05) { // Ignore middle button for now
        case 5: // Both buttons pressed, reset to defaults
            reset_perm_config(cfg);
            write_perm_config(cfg);
            blinkLED(20, 0);
            soft_reset();
            break;
        case 4: // Left button, change protocol
            cfg->cfg_data.c.proto = !(cfg->cfg_data.c.proto);
            write_perm_config(cfg);
            blinkLED(10, 0);
            soft_reset();
            break;
        case 1: // Right button, change resolution
            cfg->cfg_data.c.res = (cfg->cfg_data.c.res + 1) % 4;
            write_perm_config(cfg);
            blinkLED(3, 0);
            _delay_ms(500);
            blinkLED(cfg->cfg_data.c.res + 1, 0);
            _delay_ms(500);
            soft_reset();
            break;
        case 0: // Nothing to do
        default:
            break;   
    }
}

static void soft_reset(void) {
    wdt_enable(WDTO_15MS);  
    while(1); // This will reset the unit
}

void sleepMode(uint8_t debug) {
    if(debug) printf("sleepMode() - Sleeping!!!\n\n");

    wdt_disable();

    set_sleep_mode(SLEEP_MODE_PWR_DOWN);
    cli();

    // Set INT0 to interrupt on low level (falling edge won't work)
#if defined (__AVR_ATmega8A__)
    MCUCR &= ~(_BV(ISC01) | _BV(ISC00));
#elif defined (__AVR_ATmega328P__)
    EICRA &= ~(_BV(ISC01) | _BV(ISC00));
#endif

    // Go to sleep now...
    sleep_enable();
    sei();
    sleep_cpu();
    sleep_disable();

    // Restore interrupt on falling edge for INT0
#if defined (__AVR_ATmega8A__)
    MCUCR |= _BV(ISC01);
#elif defined (__AVR_ATmega328P__)
    EICRA |= _BV(ISC01);
#endif

#if defined (__AVR_ATmega328P__)
    wdt_enable(WDTO_4S); // Enable the watchdog to reset in 4 seconds...
#elif defined (__AVR_ATmega8A__)
    wdt_enable(WDTO_2S); // Enable the watchdog to reset in 2 seconds...
#endif    
    
    if(debug) printf("sleepMode() - Woken Up!!!\n\n");
}

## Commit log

2019-12-10 Configure for arduino
2019-12-24 Take out data management from the interrupt
2020-01-03 Add support for the middle mouse button
2020-01-03 Begin wiring up the conversion code
2020-01-11 Start fixing the proto
    [main.c]
2020-01-15 Disable code for attiny, fix programmer device
    [main.c]
2020-01-15 Remove some TODOs related to interrupts
2020-01-15 Maybe finally fix the proto?
    [main.c]
2020-01-17 Add empty kicad project
    [proto_01.kicad_pcb, proto_01.sch]
2020-01-18 Begin keeping track of TODOs
2020-01-18 Add initial schematics
    [pontag.sch]
2020-01-18 Begin creating the schematic
    [pontag.sch]
2020-01-18 Add 5V regulation
    [pontag.sch]
2020-01-18 More changes to the schematics
    [pontag.sch]
2020-01-18 More changes
    [pontag.sch]
2020-01-18 Begin wiring the MAX232
    [pontag.sch]
2020-01-19 Add connections to RS232 port and MAX232
    [pontag.sch]
2020-01-19 Additional schematics changes
    [pontag.sch]
2020-01-19 Begin assigning footprints
    [pontag.sch]
2020-01-19 Add footprint for PS/2
    [pontag.sch]
2020-01-19 More footprints
    [pontag.sch]
2020-01-19 Assigned all footprints
    [pontag.sch]
2020-01-20 Begin drawing PCB
    [pontag.kicad_pcb, pontag.sch]
2020-01-20 Draw the circuit for pontag
    [pontag.kicad_pcb]
2020-01-20 Add silkscreen
    [pontag.kicad_pcb]
2020-01-20 Fix DRC error
    [pontag.kicad_pcb]
2020-01-25 Add gerbers
2020-02-10 Make sure the led port is an output and off
2020-02-11 Begin fixing code for 8a
    [main.c]
2020-02-11 Fix UART for ATMega8A
2020-02-12 Change default device for 328p_8
2020-02-12 Moving around the documentation
    [pontag.kicad_pcb, pontag.sch]
2020-02-12 Add LED toggle when initializing the mouse
2020-02-14 Use Microsoft wheel protocol
2020-02-14 Invert option header check
    [main.c]
2020-02-15 Fix button reading at beginning
    [main.c]
2020-02-15 Enable wheel mode
2020-02-15 Set wheel movement in serial packet
2020-02-15 Add debug prints
2020-02-15 Accept 0xFA as answer to reset, add blinking to distinguish mouse type
    [main.c]
2020-02-15 Save buttons from initialization
2020-02-15 Wire up configuration change by mouse buttons
2020-02-16 Add debug strings printed when enabling debug mode via header
2020-02-16 Begin changing the schematic for SMD board
    [pontag.sch]
2020-02-16 Begin drawing SMD board
    [pontag.kicad_pcb, pontag.sch]
2020-02-16 Update schematics and PCB
    [pontag.kicad_pcb, pontag.sch]
2020-02-16 Changed some connectors
    [pontag.kicad_pcb, pontag.sch]
2020-02-16 Notify via led in case there is a detection error
    [main.c]
2020-02-17 Add pin header to disable wheel detection
2020-02-17 Organize some components
    [pontag.kicad_pcb]
2020-02-17 Go on with board routing
    [pontag.kicad_pcb, pontag.sch]
2020-02-17 Updates on SMD PCB
    [pontag.kicad_pcb]
2020-02-17 Add silkscreen text
    [pontag.kicad_pcb]
2020-02-17 Add logo to board
    [pontag.kicad_pcb]
2020-02-17 Add SMD gerbers
2020-02-18 Highlight pin names in list
2020-11-01 Removed empty kicad project
    [proto_01.kicad_pcb, proto_01.sch]
2020-11-01 Add pcb picture
2020-11-01 Add board picture to README
2020-11-02 Added licence for the PCBs
2020-11-07 Add code to read milliseconds since start
2020-12-02 Use the led to notify the user of the selected mouse config
2021-06-02 Minimal changes to silkscreen
    [pontag.kicad_pcb, pontag.sch]
2021-06-02 Rerouted some traces
    [pontag.kicad_pcb]
2021-08-19 Begin working on internal board
    [pontag.kicad_pcb, pontag.sch]
2021-08-19 Added some "not connected" points
    [pontag.sch]
2021-08-22 prepare files for internal PCB
    [pontag.kicad_pcb]
2021-08-22 Use an angled reset button
    [pontag.sch]
